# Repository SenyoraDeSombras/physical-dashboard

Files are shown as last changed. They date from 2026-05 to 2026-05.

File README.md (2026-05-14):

# Physical PC Telemetry Dashboard





A real-time, physical hardware monitoring system that bridges PC performance metrics (CPU, GPU, and VRAM) to a custom-built desktop dashboard. The system utilizes an ESP32 microcontroller to drive a magnetoelectric galvanometer (analog needle) and a 4-digit 7-segment display.

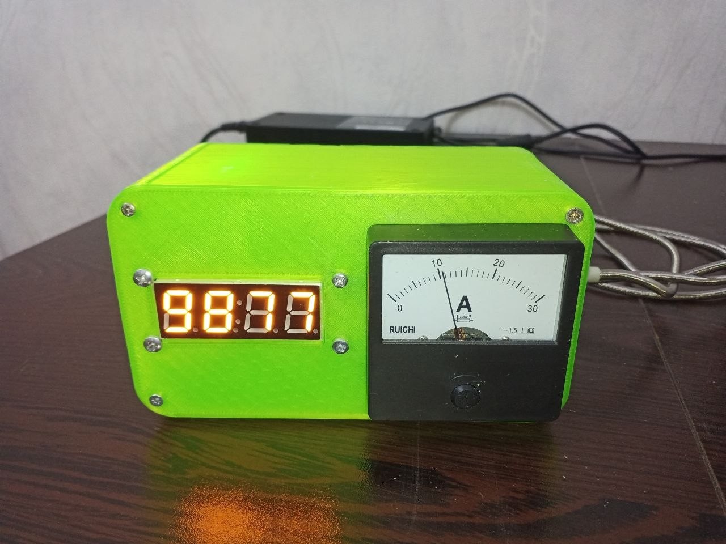
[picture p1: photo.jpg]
photo_device


## 🚀 Features

- **Real-time Monitoring**: Low-latency tracking of CPU utilization, GPU utilization, and VRAM usage.
- **Hybrid Display**: 
    - **Analog**: A galvanometer needle driven via PWM for intuitive, "analog-feel" GPU monitoring.
    - **Digital**: A 4-digit 7-segment display providing precise numerical data for CPU and VRAM.
- **Auto-Discovery**: The Python backend automatically scans COM ports to detect and handshake with the ESP32 hardware.
- **System Tray Integration**: Runs as a lightweight background process with a system tray icon for easy control.
- **Robust Communication**: Custom serial protocol with command validation and error handling.

## 🛠 Hardware Requirements

| Component | Specification | Description |
| :--- | :--- | :--- |
| **Microcontroller** | ESP32 | Main logic and PWM/Serial controller |
| **Display** | TM1637 4-Digit 7-Segment | Digital readout for CPU/VRAM |
| **Actuator** | Magnetoelectric Galvanometer | Analog needle movement |

### Pin Mapping (ESP32)
- **PWM Output (Needle)**: GPIO 14
- **TM1637 CLK**: GPIO 8
- **TM1637 DIO**: GPIO 9
### 🔌Schematic
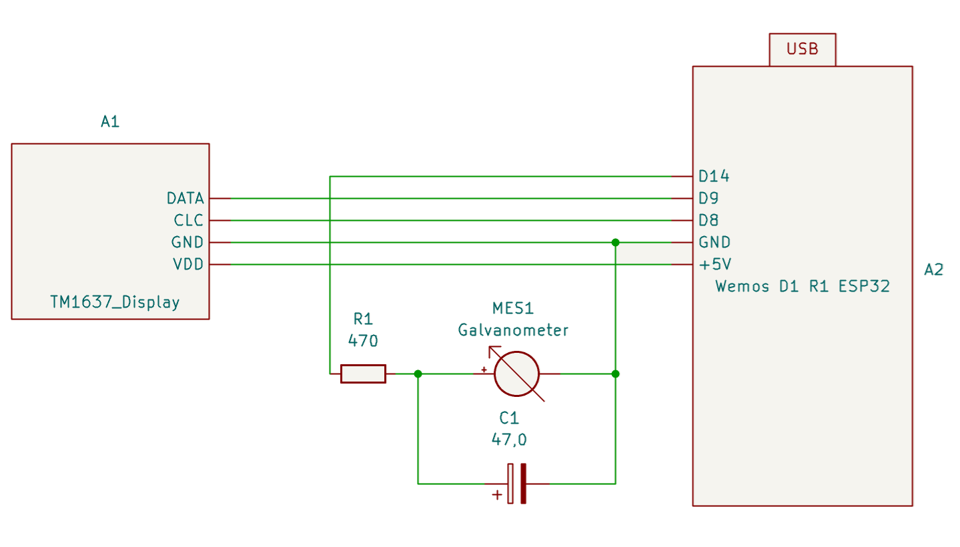
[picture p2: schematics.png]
Schematic

## 💻 Software Requirements

### Backend (Python 3.x)
- `pynvml`: NVIDIA Management Library interface.
- `psutil`: System and process utilities.
- `pyserial`: Serial communication.
- `pystray`: System tray icon integration.
- `Pillow`: Image processing for the tray icon.

### Firmware (Arduino/C++)
- `TM1637Display` library.
- ESP32 Board Support Package.

## ⚙️ Installation & Setup

### 1. Hardware Flashing
1. Open the `dashboard.ino` file in the Arduino IDE.
2. Select your ESP32 board model.
3. Connect your ESP32 via USB.
4. Click **Upload**.

### 2. Software Environment Setup
Clone this repository and install the required Python dependencies:

```bash
# Clone the repository
git clone https://github.com/SenyoraDeSombras/physical-dashboard.git
cd physical-dashboard

# Install dependencies
pip install pynvml psutil pyserial pystray Pillow
```

### 3. Running the Dashboard
Ensure your ESP32 is plugged into your PC, then run:

```bash
python dashboard_app.pyw
```

The application will scan your COM ports, perform a handshake (`Who A U?` $\rightarrow$ `DASHBRD`), and begin updating the hardware.

## 📐 System Architecture

### Communication Protocol
The system uses a text-based serial protocol for simplicity and reliability:

| Command | Target | Description |
| :--- | :--- | :--- |
| `Who A U?` | ESP32 | Handshake request from PC to verify device presence. |
| `Set NDL: <val>` | Galvanometer | Sets PWM duty cycle (0-225) for the needle. |
| `Set HIB: <val>` | 7-Seg (High) | Sets the first two digits of the 4-digit display. |
| `Set LOB: <val>` | 7-Seg (Low) | Sets the last two digits of the 4-digit display. |

### Data Flow
1. **Python Service** polls `psutil` (CPU) and `NVML` (GPU/VRAM).
2. **Data Processing**: GPU utilization is scaled for the analog needle movement.
3. **Serial Transmission**: Commands are sent over USB-Serial.
4. **ESP32 Parsing**: The firmware parses the string, validates the range, and updates the hardware registers.

## 🛡 Safety & Validation
- **Embedded Validation**: The ESP32 firmware performs bounds-checking on all incoming serial data to prevent invalid PWM duty cycles or display errors.
- **Timeout Protection**: The Python script includes a 2-second timeout during the device discovery phase to prevent blocking.

## 📝 License
Distributed under the GPL3 License. See `LICENSE` for more information.

---
**Author:** SenyoraDeSombras
**Project Role:** Lead Hardware/Software Engineer

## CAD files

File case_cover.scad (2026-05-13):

// ==========================================
// GLOBAL PARAMETERS
// ==========================================

// 1. General dimensions
int_w = 140;
int_h = 75;
int_d = 65;
wall = 1.8; 
corner_radius = 12;
fn_val = 60;

steps_depth = 0.9;

// 2. Front panel and cover mounting
cover_thick = 2;
cover_screw_inset = 7; 
body_screw_d = 2.4;      // For 3mm self-tapping screw

// 3. Ammeter (Configurable mount)
ammeter_d = 52.5;
amm_mount_r = 35.6;      // DISTANCE FROM CENTER TO HOLE (configure here)
ammeter_pos = [35, 0];   // Offset of the entire device on the cover

// 4. Seven-segment display
disp_w = 51;
disp_h = 21;
disp_pos = [-35, 0];
disp_stand_d = 4.5;
disp_stand_h = 5;

// ARRAY OF DISPLAY STANDOFF POSITIONS (relative to cutout center)
disp_standoff_coords = [
    [-(disp_w/2 + disp_stand_d/2)-0, -(disp_h/2 + disp_stand_d/2)+1.5],
    [ (disp_w/2 + disp_stand_d/2)+4, -(disp_h/2 + disp_stand_d/2)+1.5],
    [-(disp_w/2 + disp_stand_d/2)-0,  (disp_h/2 + disp_stand_d/2)-1.5],
    [ (disp_w/2 + disp_stand_d/2)+4,  (disp_h/2 + disp_stand_d/2)-1.5]
];

// 5. PCB and USB
pcb_w = 68.5;
pcb_l = 54.5;
pcb_y_offset = 13.5;         // VERTICAL PCB POSITION (offset from the edge)
pcb_stand_h = 5;
usb_offset_from_bottom = 10; 

pcb_standoff_coords = [
    [3, 18], [53.5, 3], [3, 43.5], [53.5, 45]
];

// ==========================================
// HELPER MODULES
// ==========================================

module gusset(w, h, t) {
    polyhedron(
        points = [
            [0,0,0], [w,0,0], [0,t,0], [w,t,0], // Base
            [0,0,h], [0,t,h]                    // Top
        ],
        faces = [
            [0,1,3,2], [0,4,5,2], [1,3,5,4], [0,1,4], [2,3,5]
        ]
    );
}

// For better printing of PCB stands
module hyperboloid_half_horizontal(r_waist = 10, r_base = 20, h = 30, fn = 50) {
    r_w = max(r_waist, 0.001);
    
    // b is calculated assuming 'h' is the height from waist to the top
    b = h / sqrt(pow(r_base / r_w, 2) - 1);
    
    difference() {
        rotate_extrude($fn = 60) {
            polygon(
                concat(
                    // Center axis points (waist to top)
                    [ [0, 0], [0, -h] ],
                    
                    // Generate the curve from top down to waist (y=0)
                    [ for (i = [0 : fn]) 
                        let (
                            y = -1 * (h - (i/fn) * h),
                            x = r_w * sqrt(1 + pow(y/b, 2))
                        ) 
                        [x, y] 
                    ]
                )
            );
        }
        translate([0, 0, -1.8 - 3]) {
            cylinder(d = 3.2, h = 12, $fn = 32);
        }
    }
}

module standoff_through_all(h, hole_d, base_d, surface_thick) {
    difference() {
        union() {
            cylinder(d1 = base_d + 0.4, d2 = base_d, h = h, $fn = 32);
            rotate_extrude($fn = 52) { 
                translate([2, 0, 0]) // 1. Shift the circle from the center (torus radius)
                    circle(r = 0.009);
            }
        }
        translate([0, 0, -surface_thick - 1])
            cylinder(d = hole_d, h = h + surface_thick + 2, $fn = 32);
    }
}

module main_shape(w, h, d, r) {
    hull() {
        translate([r, r, 0]) cylinder(r = r, h = d, $fn = fn_val);
        translate([w - r, r, 0]) cylinder(r = r, h = d, $fn = fn_val);
        translate([r, h - r, 0]) cylinder(r = r, h = d, $fn = fn_val);
        translate([w - r, h - r, 0]) cylinder(r = r, h = d, $fn = fn_val);
    }
}

// ==========================================
// MAIN BODY
// ==========================================

module body() {
    ext_w = int_w + 2 * wall;
    ext_h = int_h + 2 * wall;
    ext_d = int_d + wall;

    difference() {
        difference() {
            main_shape(ext_w, ext_h, ext_d, corner_radius);
            for(x = [25, ext_w - 25], z = [20, ext_d - 20]) {
                translate([x, -5 + steps_depth, z]) 
                    rotate([-90, 0, 0]) 
                    cylinder(d = 10, h = 5, $fn = 32);
            }
        }
        
        translate([wall, wall, wall])
            main_shape(int_w, int_h, int_d + 10, corner_radius - wall);
            
        // USB hole (tied to pcb_y_offset)
        translate([ext_w - wall - 1, wall + pcb_y_offset + usb_offset_from_bottom, wall + pcb_stand_h + 2])
            cube([wall + 2, 12, 6]);

        for(x = [cover_screw_inset, ext_w - cover_screw_inset], 
            y = [cover_screw_inset, ext_h - cover_screw_inset]) {
            
            translate([x, y, ext_d - 15])
                cylinder(d = body_screw_d, h = 16, $fn = 32);
        }
        
        translate([ext_w - wall - pcb_w, wall + pcb_y_offset, wall]) {
            for(pos = pcb_standoff_coords) {
                translate([pos[0], pos[1], -wall - 1])
                    cylinder(d = 3.2, h = wall + 2, $fn = 32);
            }
        }
    }

    for(x = [cover_screw_inset, ext_w - cover_screw_inset], 
        y = [cover_screw_inset, ext_h - cover_screw_inset]) {
        
        translate([x, y, wall]) {
            difference() {
                cylinder(d = 8, h = ext_d - wall, $fn = 32);
                translate([0, 0, ext_d - wall - 15])
                    cylinder(d = body_screw_d, h = 16, $fn = 32);
            }
            
            dir_x = (x < ext_w/2) ? -1 : 1;
            dir_y = (y < ext_h/2) ? -1 : 1;
            
            translate([0, -2/2, 0]) 
                mirror([dir_x == 1 ? 1 : 0, 0, 0])
                gusset(8, 20, 2); 
            
            translate([-2/2, 0, 0])
                rotate([0, 0, 90])
                mirror([dir_y == 1 ? 1 : 0, 0, 0])
                gusset(8, 20, 2);
        }
    }

    // PCB standoffs (position depends on pcb_y_offset)
    translate([ext_w - wall - pcb_w, wall + pcb_y_offset, wall]) {
        for(pos = pcb_standoff_coords) {
            translate([pos[0], pos[1], 0]) {
                standoff_through_all(pcb_stand_h, 3.2, 4.5, wall);
            }
            translate([pos[0], pos[1], 2.8]) {
                hyperboloid_half_horizontal(r_waist = 2.2, r_base = 3.5, h = 3, fn = 50); 
            }
        }
    }
}

// ==========================================
// FRONT COVER
// ==========================================

module cover() {
    ext_w = int_w + 2 * wall;
    ext_h = int_h + 2 * wall;

    difference() {
        union() {
            main_shape(ext_w, ext_h, cover_thick, corner_radius);
            
            translate([ext_w/2 + disp_pos[0], ext_h/2 + disp_pos[1], cover_thick]) {
                for(pos = disp_standoff_coords) {
                    translate([pos[0], pos[1], 0]) 
                        standoff_through_all(disp_stand_h, 3.2, disp_stand_d, cover_thick);
                    translate([pos[0], pos[1], 2.8]) {
                        hyperboloid_half_horizontal(r_waist = 2.2, r_base = 3.5, h = 3, fn = 50); 
                    }
                }
            }
        }
        
        translate([ext_w/2 + ammeter_pos[0], ext_h/2 + ammeter_pos[1], -1]) {
            cylinder(d = ammeter_d, h = cover_thick + 2, $fn = fn_val);
            off = amm_mount_r * 0.7071;
            for(ix = [-1, 1], iy = [-1, 1])
                translate([ix * off, iy * off, 0])
                    cylinder(d = 3.8, h = cover_thick + 2, $fn = 32);
        }
        
        for(x = [cover_screw_inset, ext_w - cover_screw_inset], 
            y = [cover_screw_inset, ext_h - cover_screw_inset]) {
            
            translate([x, y, -1])
                cylinder(d = 3.4, h = cover_thick + 2, $fn = 32);
        }

        translate([ext_w/2 + disp_pos[0], ext_h/2 + disp_pos[1], -1]) {
            for(pos = disp_standoff_coords) {
                translate([pos[0], pos[1], 0])
                    cylinder(d = 3.2, h = cover_thick + 2, $fn = 32);
            }
        }
        
        translate([ext_w/2 + disp_pos[0] - disp_w/2, ext_h/2 + disp_pos[1] - disp_h/2, -1])
            cube([disp_w, disp_h, cover_thick + 8]);
    }
}

// ==========================================
// RENDER
// ==========================================

//body();

// translate([0, 0, int_d + 30]) 
     cover();

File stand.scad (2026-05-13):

cylinder(d = 9.8, h = 3, $fn = 50);

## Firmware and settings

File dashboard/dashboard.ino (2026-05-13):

/**
 * @file dashboard.ino
 * @author Alicia aka SenyoraDeSombras
 * @brief Parses commands via Serial and updates PWM duty cycle and 7segment dispaly.
 * 
 * Hardware: ESP32
 * Platform: Arduino
 */

#include <Arduino.h>
#include <TM1637Display.h>

// --- Configuration ---
// Using constexpr for type-safety and efficiency
constexpr uint8_t PWM_PIN = D14;          // GPIO pin to drive the output
constexpr uint32_t BAUD_RATE = 9600;  // Standard high-speed baud
constexpr char PREFIX_NDL[] = "Set NDL: ";  // The command prefix for needle
constexpr char PREFIX_HIB[] = "Set HIB: ";  // The command prefix for high byte on 7seg indicator
constexpr char PREFIX_LOB[] = "Set LOB: ";  // The command prefix for low byte on 7seg indicator
constexpr char PREFIX_REQ[] = "Who A U?";  // The command prefix device detect
constexpr size_t PREFIX_LEN = sizeof(PREFIX_NDL) - 1;
//Display set up
#define CLK D8
#define DIO D9

TM1637Display display(CLK, DIO);

// --- Global State ---
uint8_t currentNDLValue = 0;
uint8_t currentHIBValue = 88;
uint8_t currentLOBValue = 88;
/**
 * @brief Handles the parsing and logic of the incoming serial string.
 * @param input The raw string received from Serial
 */
void processSerialCommand(String input) {
    // 1. Remove potential carriage returns/newlines from the end
    input.trim();
    if (input.startsWith(PREFIX_REQ)) {
		while (!Serial && millis() < 2000);
        Serial.println(F("DASHBRD"));
    }
    // 2. Check if the string starts with the required prefix
    if (input.startsWith(PREFIX_NDL) || input.startsWith(PREFIX_HIB) || input.startsWith(PREFIX_LOB)) {
        
        // 3. Extract the substring following the prefix
        String valueStr = input.substring(PREFIX_LEN);
        
        // 4. Convert to integer
        int parsedValue = valueStr.toInt();

        // 5. Validation (Safety first in embedded!)
        // Ensure the value is within the valid 8-bit PWM range [0, 255]
        // For needle
        if (input.startsWith(PREFIX_NDL) && parsedValue >= 0 && parsedValue <= 225) {
            currentNDLValue = static_cast<uint8_t>(parsedValue);
            
            // Apply the PWM signal
            analogWrite(PWM_PIN, currentNDLValue);

      
        } 
        // For high byte on 7seg indicator
        if (input.startsWith(PREFIX_HIB) && parsedValue >= 0 && parsedValue <= 99) {
            currentHIBValue = static_cast<uint8_t>(parsedValue);
            
            // Apply the PWM signal
            display.showNumberDec(currentHIBValue, true, 2, 0);  

           
        } 
        // For low byte on 7seg indicator
        if (input.startsWith(PREFIX_LOB) && parsedValue >= 0 && parsedValue <= 99) {
            currentLOBValue = static_cast<uint8_t>(parsedValue);
            
            // Apply the PWM signal
            display.showNumberDec(currentLOBValue, true, 2, 2);  

        } 
    } 
}

void setup() {
    // Initialize Hardware
    pinMode(PWM_PIN, OUTPUT);
    analogWrite(PWM_PIN, 0); // Start with 0 duty cycle

    // Initialize Communication
    Serial.begin(BAUD_RATE);
    
    // Wait for Serial to stabilize (important for native USB ESP32-S3/C3)
    while (!Serial && millis() < 2000);

    display.setBrightness(0x0f);
    uint8_t data[] = { 0xff, 0xff, 0xff, 0xff };
    display.setSegments(data);
}

void loop() {
    // Non-blocking check for serial data
    if (Serial.available() > 0) {
        // Read until newline character
        String incomingBuffer = Serial.readStringUntil('\n');
        
        // Delegate logic to the processor
        processSerialCommand(incomingBuffer);
    }

}

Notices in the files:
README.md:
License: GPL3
